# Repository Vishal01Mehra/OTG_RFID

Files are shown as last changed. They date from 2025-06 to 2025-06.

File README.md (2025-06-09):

# STM32G0 + MFRC522 RFID Reader
<p align="center">
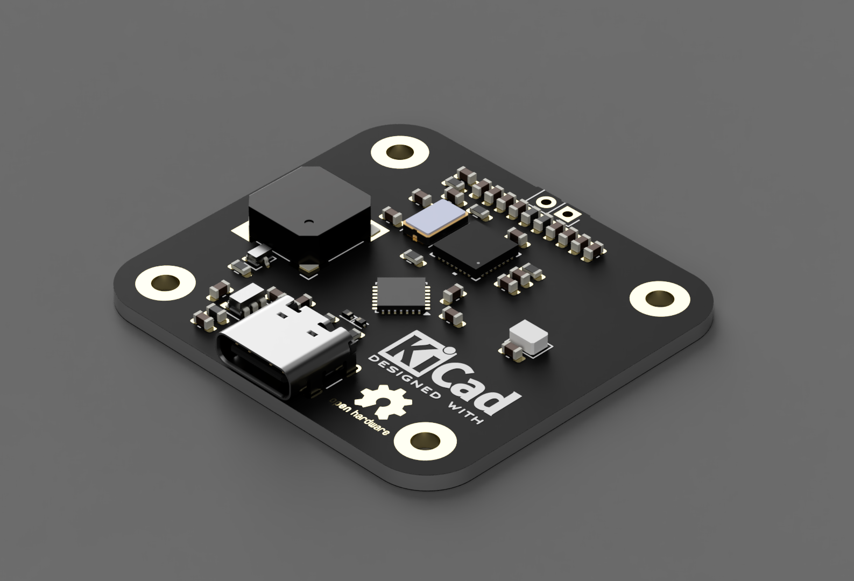
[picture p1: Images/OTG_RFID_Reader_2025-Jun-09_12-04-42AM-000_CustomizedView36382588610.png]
  
</p>

#### This repository provides code and hardware documentation for interfacing the **MFRC522 RFID reader** with an **STM32G0 series microcontroller** over SPI. The firmware initializes the MFRC522, detects RFID cards, and prints their UID over UART. It also includes support for an **addressable RGB LED** (e.g., WS2812B) and a **buzzer** for feedback.

##  Features
- Uses STM32Cube HAL for SPI, GPIO, and TIM
- Reads MIFARE cards (UID output)
- Controls an addressable RGB LED (PA3)
- Activates buzzer on card detection (PA2)
- Compatible with MFRC522 13.56 MHz modules
- Designed for STM32G0xx (e.g., STM32G071, STM32G031)
- Antenna is tuned for best theoretical range (10–15 cm)

>  **Note:** Higher read ranges (>15 cm) are only possible with UHF RFID chipsets (e.g., EPC Gen2, ISO18000-6C), which are significantly more expensive. This project limits itself to a 13.56 MHz MFRC522-based design due to a target **cost constraint of ₹500**, making UHF solutions out of scope.

---

##  Repository Structure
```
├── Core
│   ├── Inc
│   │   └── mfrc522.h           # MFRC522 header file
│   └── Src
│       └── mfrc522.c           # MFRC522 implementation
├── Drivers
│   └── STM32G0xx_HAL_Driver    # HAL drivers
├── README.md                   # This file
├── main.c                      # Main application logic
├── LICENSE                     # GNU GPL v3 license
└── .ioc                        # STM32CubeMX project file
```

---

##  Hardware Connections
### SPI Interface
| MFRC522 Pin | STM32G0 Pin | Description |
|---|---|---|
| SDA (SS) | PA4 | SPI Chip Select |
| SCK | PA5 | SPI Clock |
| MOSI | PA7 | SPI MOSI |
| MISO | PA6 | SPI MISO |
| RST | PB0 | Reset Pin |
| 3.3V | 3.3V | Power |
| GND | GND | Ground |

### Other IOs
| Component | STM32G0 Pin | Notes |
|---|---|---|
| Buzzer | PA2 | On for tag detected |
| RGB LED (WS2812B) | PA3 | 1-wire protocol |

---

##  Example Output (USB)
```
MFRC522 Reader Initialized
Scan RFID...
UID: DE AD BE EF
```

---

##  Getting Started

### Prerequisites
- STM32CubeIDE or STM32CubeMX
- ST-LINK or compatible debugger
- MFRC522 RFID Module
- WS2812B LED
- Buzzer (active or transistor-driven passive)

### Build & Flash
1. Clone this repo: `https://github.com/Vishal01Mehra/OTG_RFID`
2. Open the `.ioc` file in STM32CubeIDE
3. Generate code and build
4. Flash to STM32G0 MCU

### Dependencies
- STM32 HAL Drivers (auto-imported with `.ioc`)

> 🔧 **Note:** Software is coming soon. Code files will be released as part of the first firmware version.

---

##  References
- [MFRC522 Datasheet](https://www.nxp.com/docs/en/data-sheet/MFRC522.pdf)
- [STM32G0 Reference Manual](https://www.st.com/resource/en/reference_manual/dm00371828.pdf)
- [WS2812B Timing](https://cdn-shop.adafruit.com/datasheets/WS2812B.pdf)

---

##  License
This project is licensed under the **GNU General Public License v3.0** - see the [LICENSE](LICENSE) file for details.

---

## Author
**Vishal Mehra** - Mehra Autonomous Systems Pvt. Ltd.

---

Feel free to contribute or raise issues via GitHub.

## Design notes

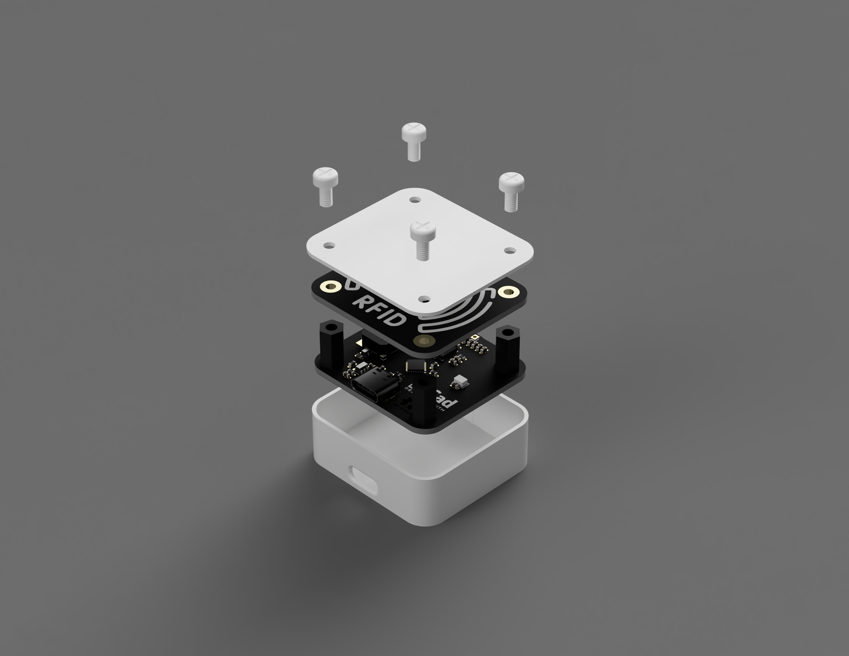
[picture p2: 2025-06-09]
Images/OTG_RFID_Reader_2025-Jun-09_12-10-32AM-000_CustomizedView28669614797.png

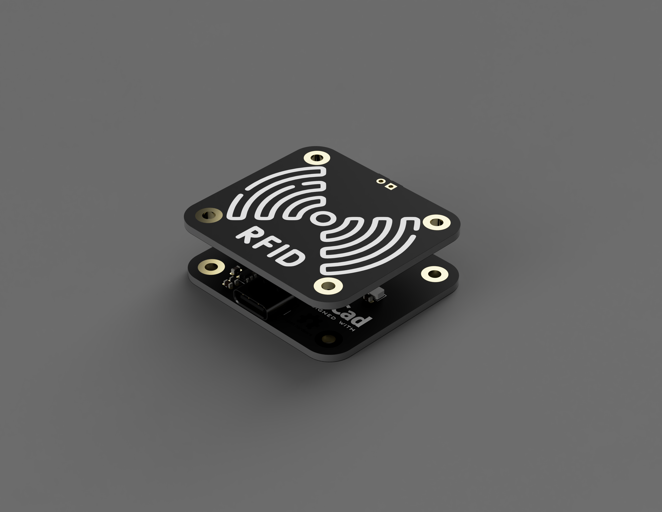
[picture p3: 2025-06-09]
Images/OTG_RFID_Reader_2025-Jun-09_12-07-47AM-000_CustomizedView14666808826.png

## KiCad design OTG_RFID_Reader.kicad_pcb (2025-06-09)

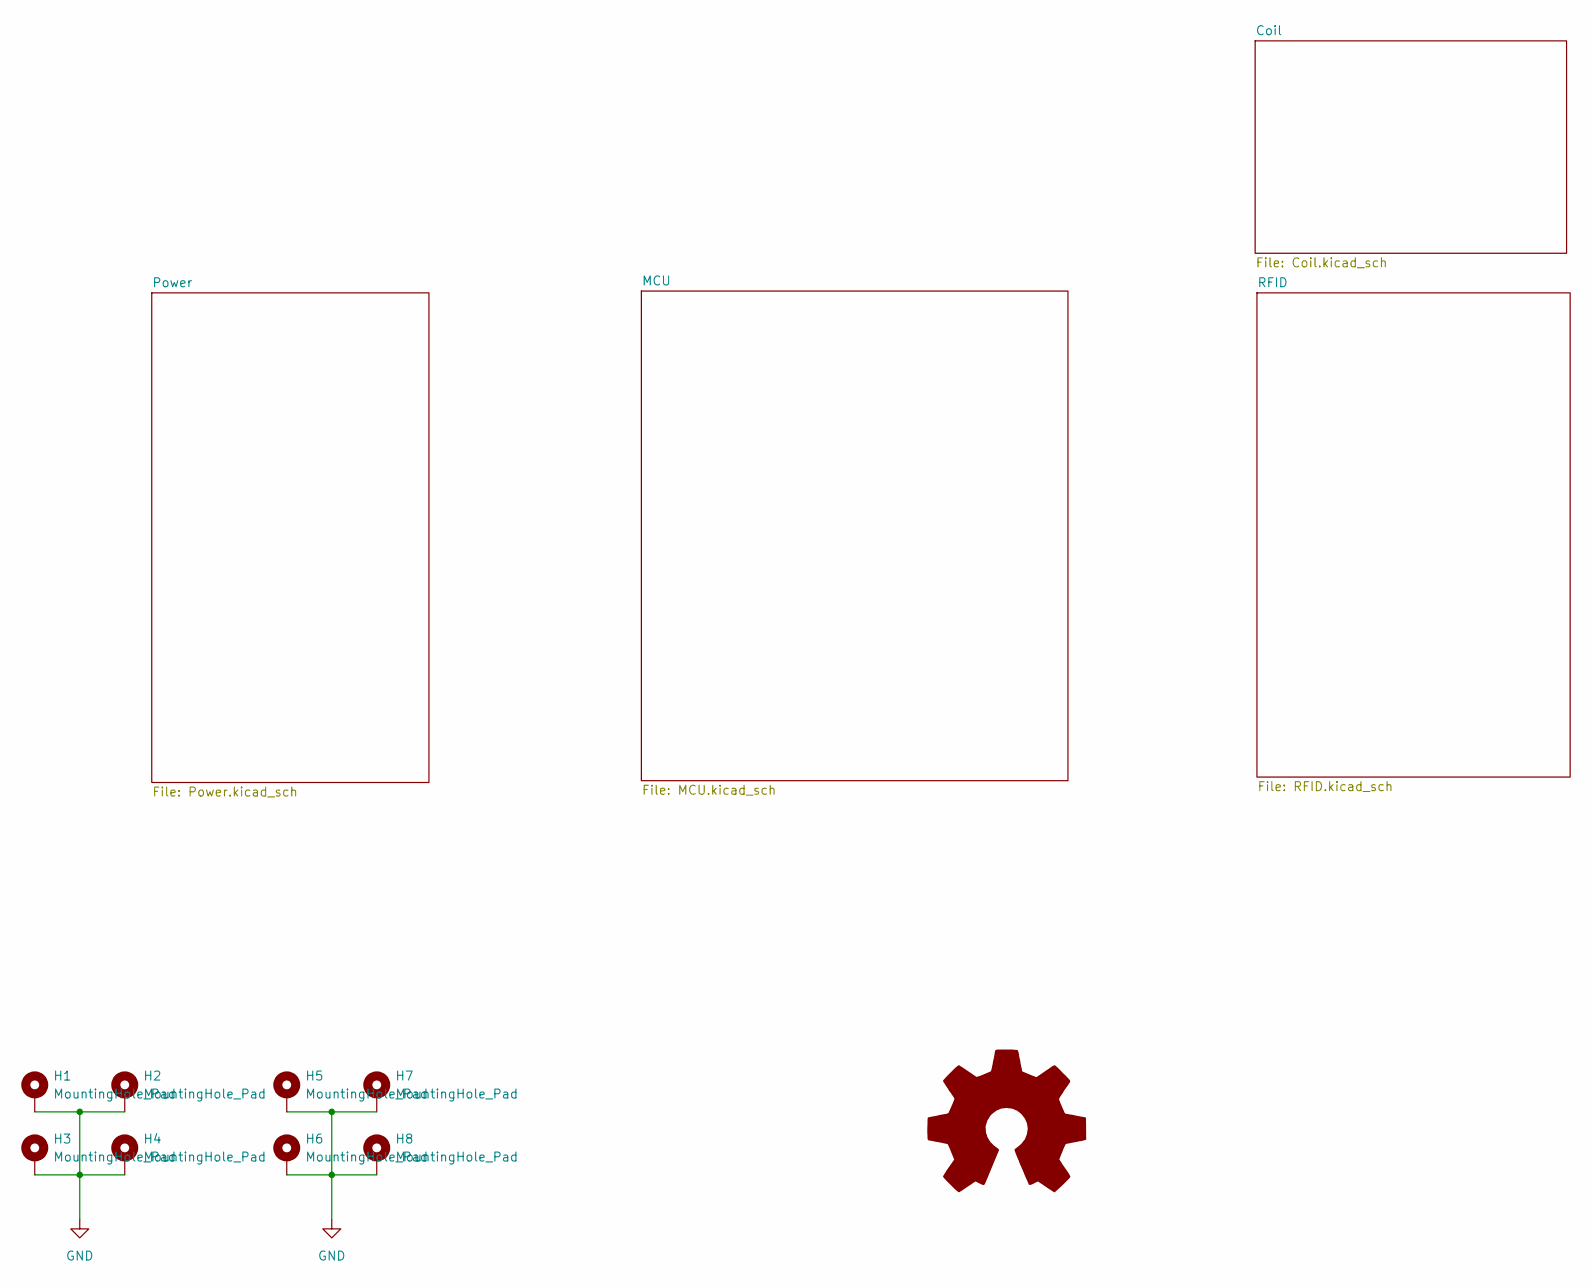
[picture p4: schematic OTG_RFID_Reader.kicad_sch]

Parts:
H1, H2, H3, H4, H5, H6, H7, H8: MountingHole_Pad; MountingHole_2.5mm_Pad

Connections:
GND: H1.1, H2.1, H3.1, H4.1, H5.1, H6.1, H7.1, H8.1; also elsewhere on the board

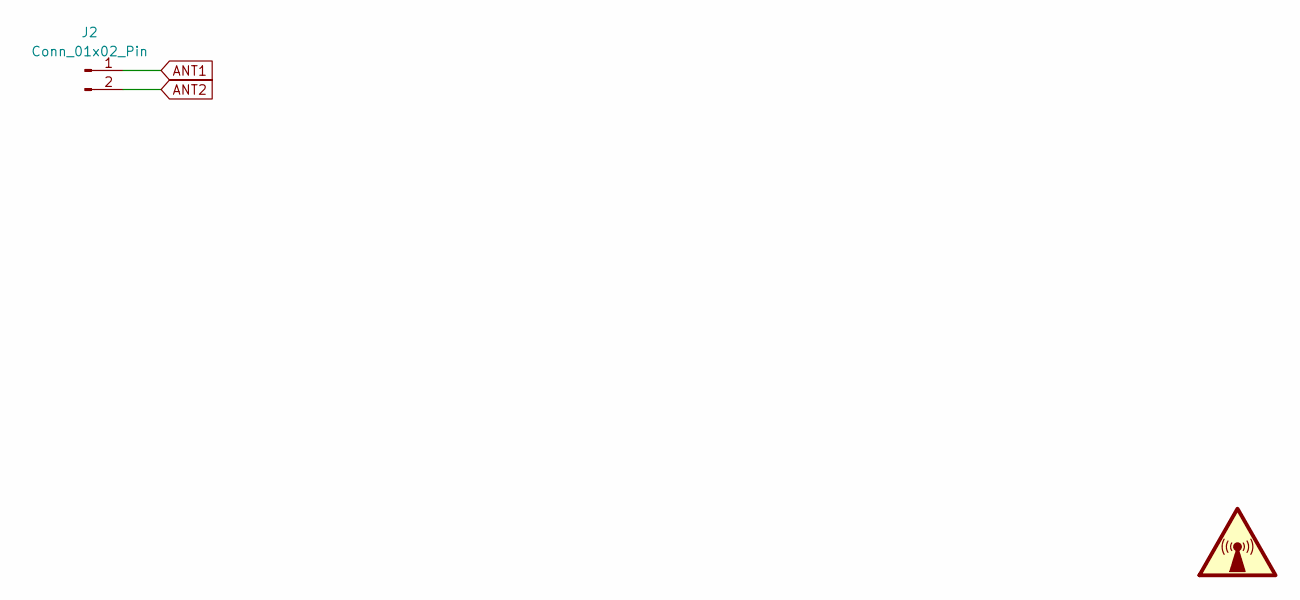
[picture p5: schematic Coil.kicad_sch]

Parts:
J2: Conn_01x02_Pin; PinSocket_1x02_P2.54mm_Vertical

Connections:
ANT1: J2.1; also elsewhere on the board
ANT2: J2.2; also elsewhere on the board

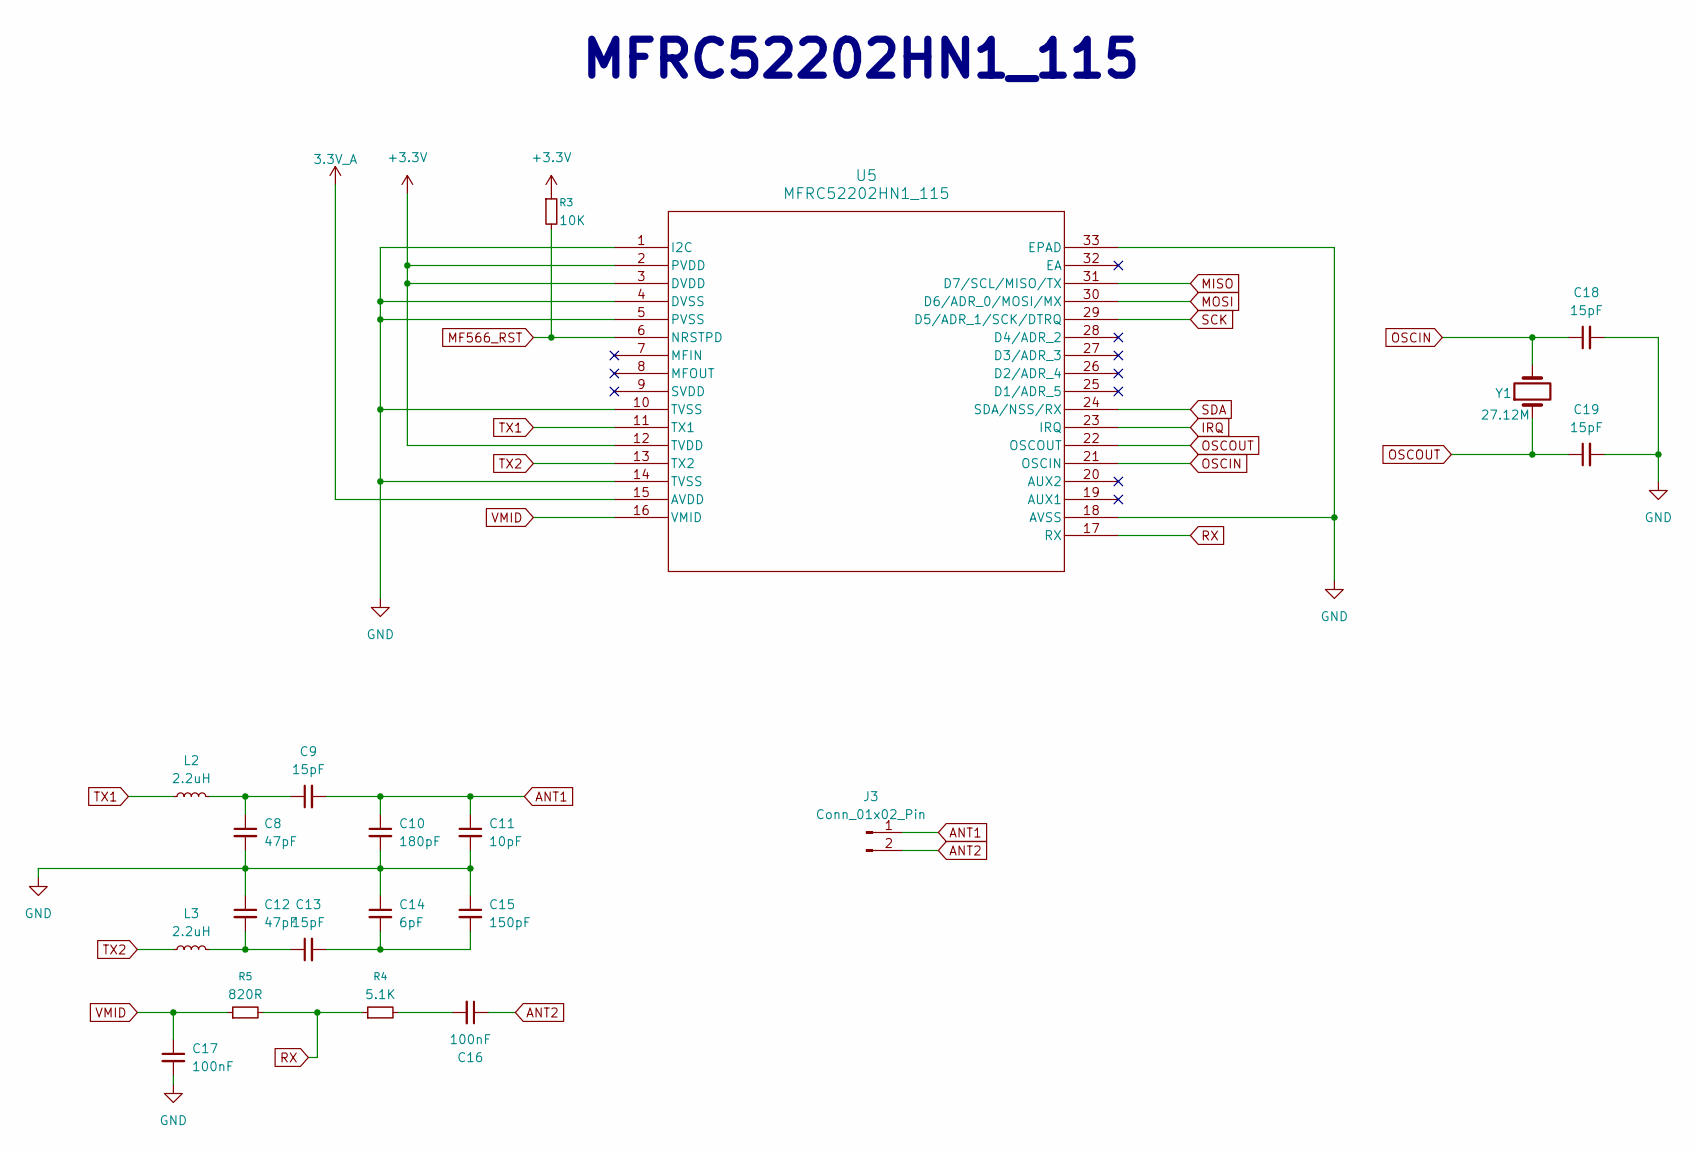
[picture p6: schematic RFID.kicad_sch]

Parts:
C8, C12: 47pF; C_0603_1608Metric
C9, C13, C18, C19: 15pF; C_0603_1608Metric
C10: 180pF; C_0603_1608Metric
C11: 10pF; C_0603_1608Metric
C14: 6pF; C_0603_1608Metric
C15: 150pF; C_0603_1608Metric
C16, C17: 100nF; C_0603_1608Metric
J3: Conn_01x02_Pin; PinSocket_1x02_P2.54mm_Vertical
L2, L3: 2.2uH; L_0603_1608Metric
R3: 10K; R_0603_1608Metric
R4: 5.1K; R_0603_1608Metric
R5: 820R; R_0603_1608Metric
U5: MFRC52202HN1_115; HVQFN32_SOT617-1_NXP
Y1: 27.12M; Crystal_SMD_TXC_7A-2Pin_5x3.2mm

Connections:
3.3V_A: U5.15 (AVDD); also elsewhere on the board
+3.3V: R3.1, U5.2 (PVDD), U5.3 (DVDD), U5.12 (TVDD); also elsewhere on the board
ANT1: C9.2, C10.1, C11.1, J3.1; also elsewhere on the board
ANT2: C16.1, J3.2; also elsewhere on the board
GND: C8.2, C10.2, C11.2, C12.1, C14.1, C15.1, C17.2, C18.2, C19.2, U5.1 (I2C), U5.4 (DVSS), U5.5 (PVSS), U5.10 (TVSS), U5.14 (TVSS), U5.18 (AVSS), U5.33 (EPAD); also elsewhere on the board
IRQ: U5.23 (IRQ)
MF566_RST: R3.2, U5.6 (NRSTPD)
MISO: U5.31 (D7/SCL/MISO/TX); also elsewhere on the board
MOSI: U5.30 (D6/ADR_0/MOSI/MX); also elsewhere on the board
unnamed: C8.1, C9.1, L2.2
unnamed: C12.2, C13.1, L3.2
unnamed: C13.2, C14.2, C15.2
unnamed: C16.2, R4.2
OSCIN: C18.1, U5.21 (OSCIN), Y1.2
OSCOUT: C19.1, U5.22 (OSCOUT), Y1.1
RX: R4.1, R5.2, U5.17 (RX)
SCK: U5.29 (D5/ADR_1/SCK/DTRQ); also elsewhere on the board
SDA: U5.24 (SDA/NSS/RX); also elsewhere on the board
TX1: L2.1, U5.11 (TX1)
TX2: L3.1, U5.13 (TX2)
VMID: C17.1, R5.1, U5.16 (VMID)

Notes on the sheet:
MFRC52202HN1_115

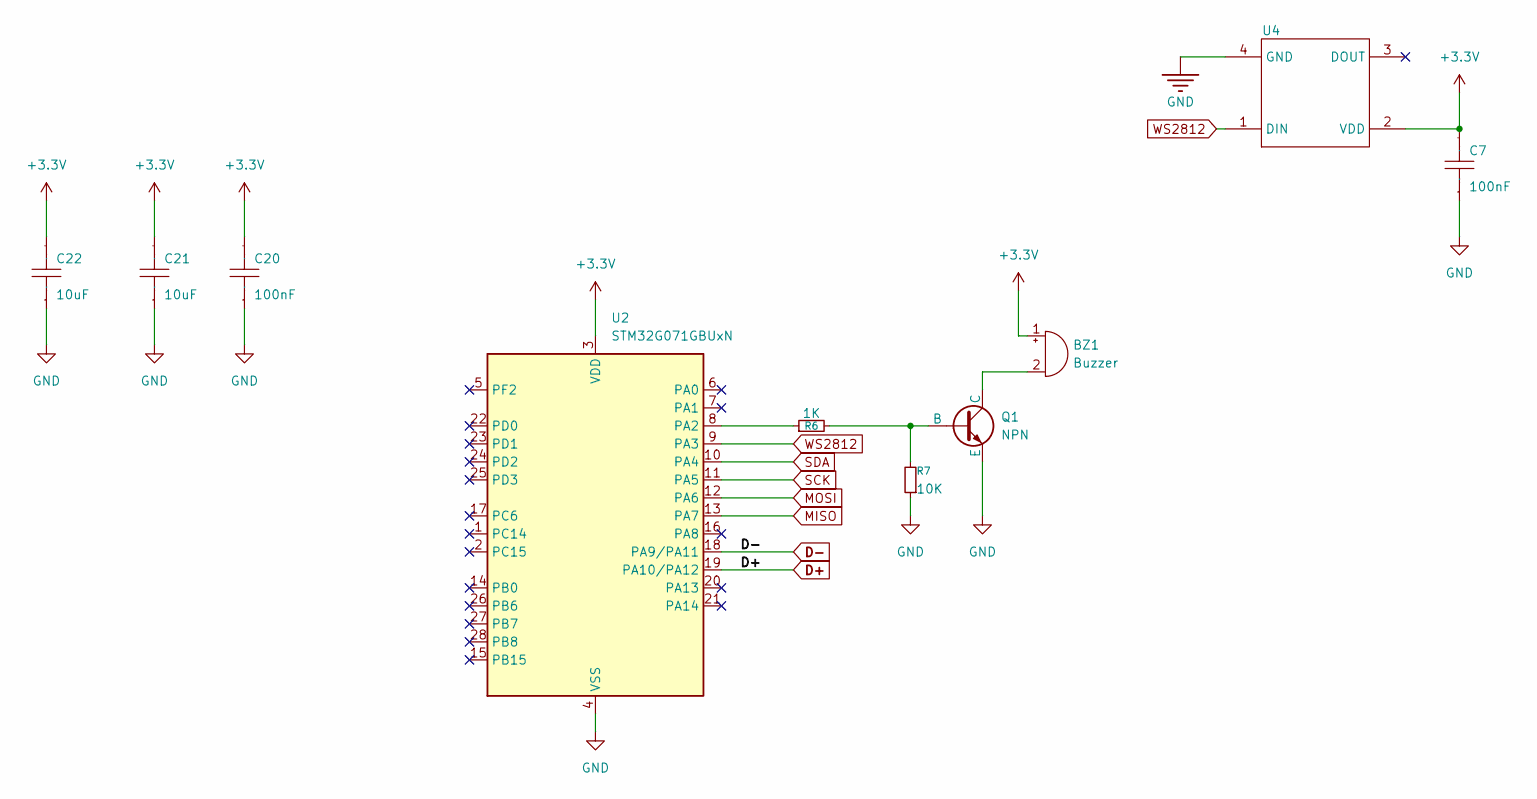
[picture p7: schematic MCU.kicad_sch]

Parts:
BZ1: Buzzer; MagneticBuzzer_CUI_CMT-8504-100-SMT
C7, C20: 100nF; C_0603_1608Metric
C21, C22: 10uF; C_0603_1608Metric
Q1: NPN; SOT-323_SC-70
R6: 1K; R_0603_1608Metric
R7: 10K; R_0603_1608Metric
U2: STM32G071GBUxN; QFN-28_4x4mm_P0.5mm
U4: LED_WS2812B-2020_PLCC4_2.0x2.0mm

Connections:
+3.3V: BZ1.1 (+), C7.2, C20.2, C21.2, C22.2, U2.3 (VDD), U4.2 (VDD); also elsewhere on the board
D+: U2.19 (PA10/PA12); also elsewhere on the board
D-: U2.18 (PA9/PA11); also elsewhere on the board
GND: C7.1, C20.1, C21.1, C22.1, Q1.3 (E), R7.1, U2.4 (VSS), U4.4 (GND); also elsewhere on the board
MISO: U2.13 (PA7); also elsewhere on the board
MOSI: U2.12 (PA6); also elsewhere on the board
unnamed: BZ1.2 (-), Q1.1 (C)
unnamed: Q1.2 (B), R6.2, R7.2
unnamed: R6.1, U2.8 (PA2)
SCK: U2.11 (PA5); also elsewhere on the board
SDA: U2.10 (PA4); also elsewhere on the board
WS2812: U2.9 (PA3), U4.1 (DIN)

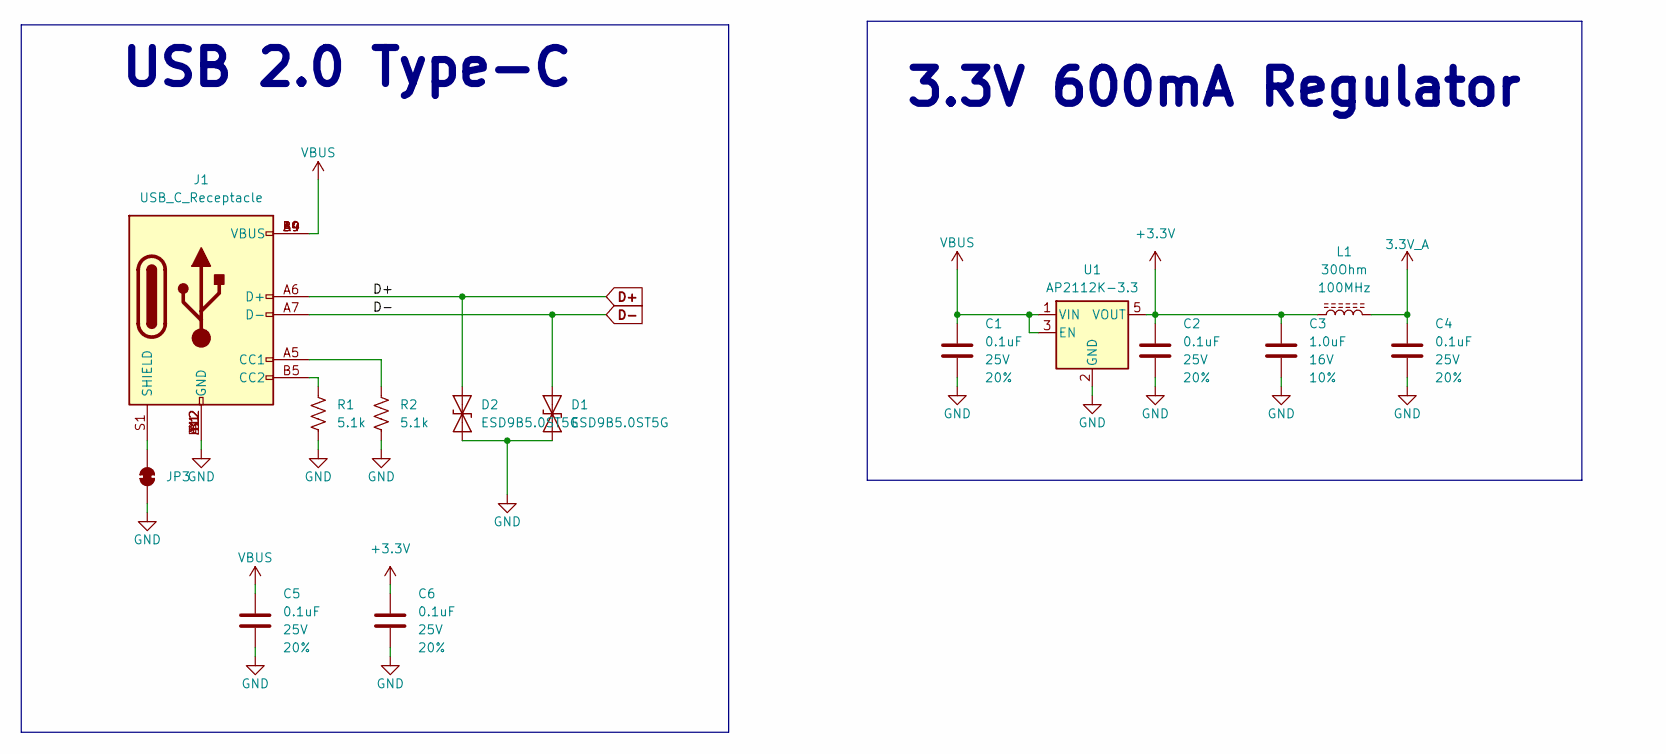
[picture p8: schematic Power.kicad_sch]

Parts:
C1, C2, C4, C5, C6: 0.1uF; C_0603_1608Metric; Voltage 25V; Tolerance 20%
C3: 1.0uF; C_0603_1608Metric; Voltage 16V; Tolerance 10%
D1, D2: ESD9B5.0ST5G; D_SOD-923
J1: USB_C_Receptacle; USB_C_Receptacle_GCT_USB4105-xx-A_16P_TopMnt_Horizontal
JP3: SolderJumper-2_P1.3mm_Bridged2Bar_RoundedPad1.0x1.5mm
L1: 30Ohm; L_0603_1608Metric
R1, R2: 5.1k; R_0603_1608Metric
U1: AP2112K-3.3; SOT-23-5_HandSoldering

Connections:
3.3V_A: C4.1, L1.2; also elsewhere on the board
+3.3V: C2.1, C3.1, C6.1, L1.1, U1.5 (VOUT); also elsewhere on the board
D+: D2.1 (A1), J1.A6 (D+), J1.B6 (D+); also elsewhere on the board
D-: D1.1 (A1), J1.A7 (D-), J1.B7 (D-); also elsewhere on the board
GND: C1.2, C2.2, C3.2, C4.2, C5.2, C6.2, D1.2 (A2), D2.2 (A2), J1.A1 (GND), J1.A12 (GND), J1.B1 (GND), J1.B12 (GND), JP3.1 (A), R1.2, R2.2, U1.2 (GND); also elsewhere on the board
unnamed: J1.A5 (CC1), R2.1
unnamed: J1.B5 (CC2), R1.1
unnamed: J1.S1 (SHIELD), JP3.2 (B)
VBUS: C1.1, C5.1, J1.A4 (VBUS), J1.A9 (VBUS), J1.B4 (VBUS), J1.B9 (VBUS), U1.1 (VIN), U1.3 (EN)

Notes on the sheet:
3.3V 600mA Regulator
USB 2.0 Type-C

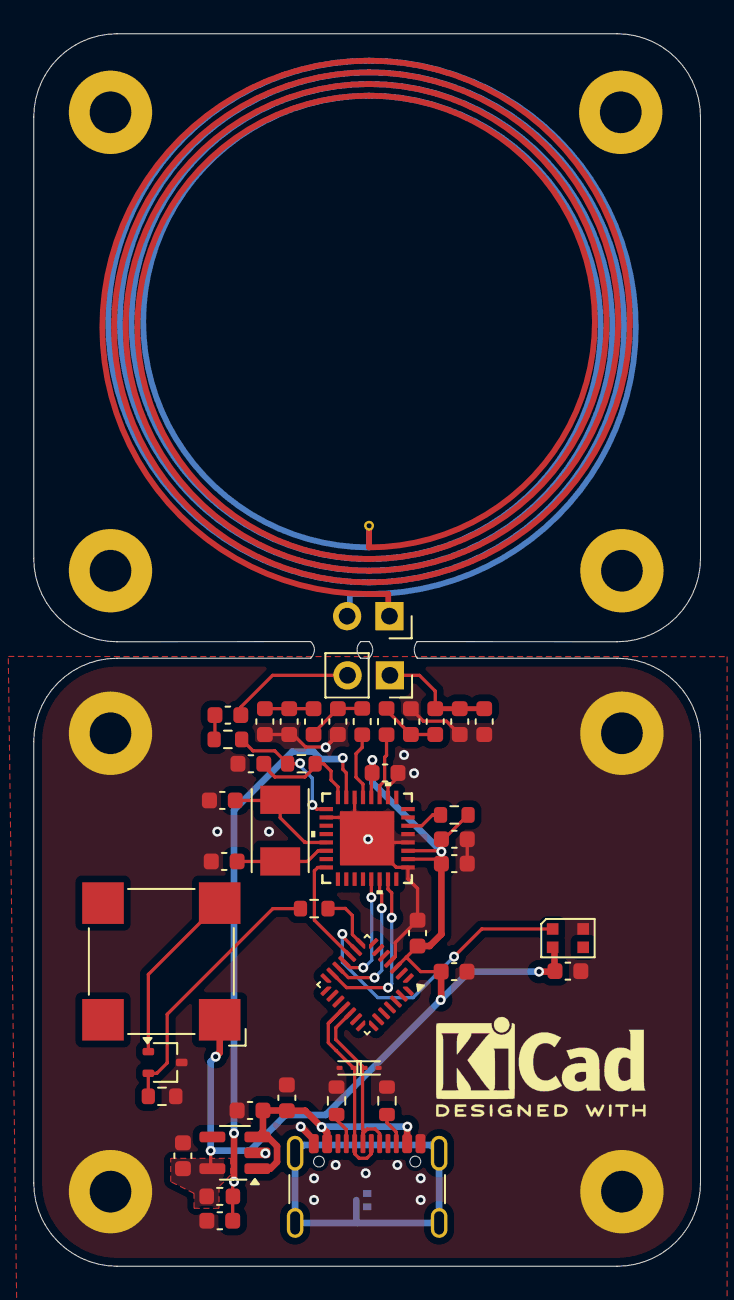
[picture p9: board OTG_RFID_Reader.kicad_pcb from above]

Board: 2 copper layers, 40.0 x 73.9 mm, 53 parts (1 on the bottom side), 30 nets.
